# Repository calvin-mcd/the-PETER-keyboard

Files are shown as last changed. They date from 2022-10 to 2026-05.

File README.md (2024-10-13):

# the PETER keyboard

compact 60ish keyboard inspired by 40s layouts & formfactors

I designed this keyboard after asking my friend Peter what his ideal keyboard would be. His answer was:"Ehm... I like numbers!". So I tried to make a board that keeps the functionality of a 60% keyboard while offering it in a 40s inspired form factor.

It takes inspiration from ai03’s [UT47.2](https://github.com/ai03-2725/UT47.2) and EODesigns\#4352’s [Humble40](https://geekhack.org/index.php?topic=112927.0) as well as trash man\#6005’s [v4n4g0n](https://trashman.wiki/keyboards/v4n4g0n) and NoahK\#1290’s [Monorail](https://trashman.wiki/community/pcbs/monorail) pcbs.

The case is based on rain\#3950's [mfr2](https://github.com/rainkeebs/mfr2) and has been edited by Gizzle\#9369 to allow for bottom mounting inspired by projectcain\#5265's [vault35](https://mechvault.net/products/vault-35-mini-keyboard)

## Layout

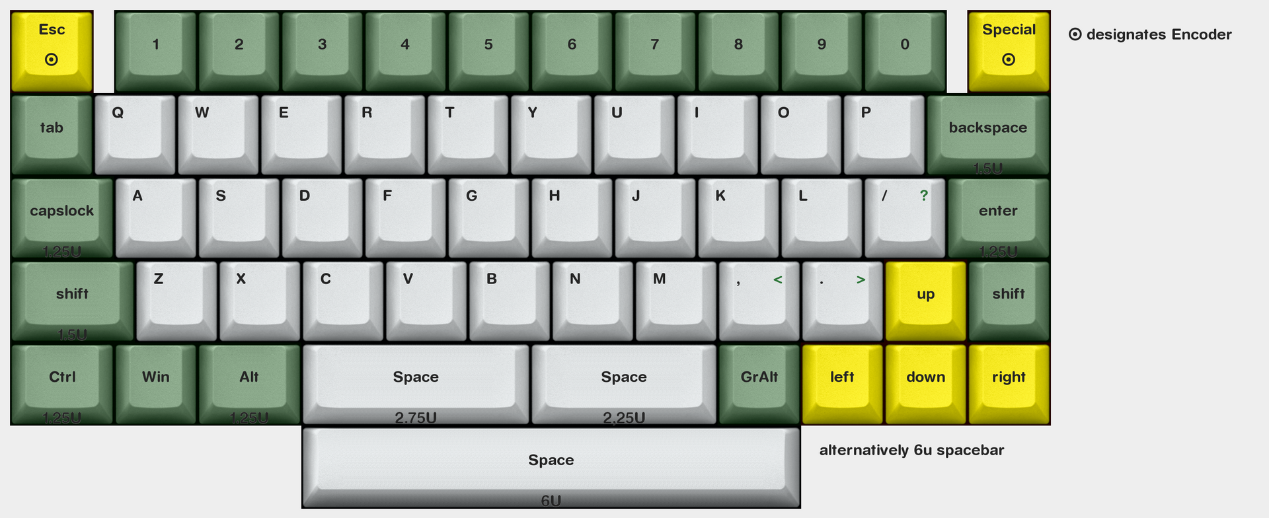
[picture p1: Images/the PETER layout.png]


[Link](https://www.keyboard-layout-editor.com/#/gists/bfbfb0e68d74f1cbb328a13727df050d)

## Pictures

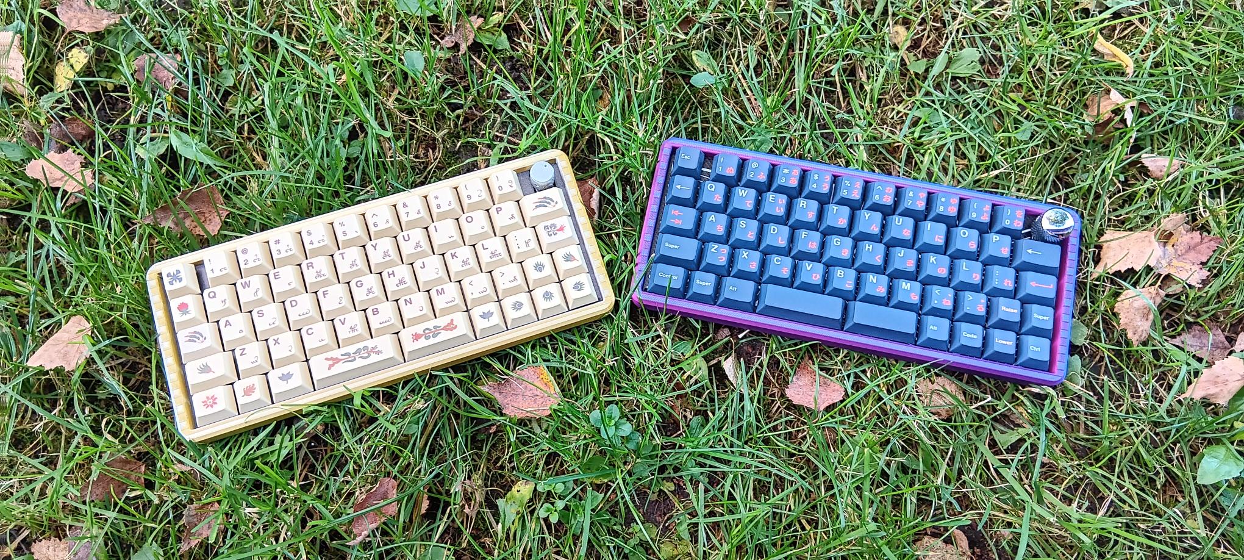
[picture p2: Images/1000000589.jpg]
  
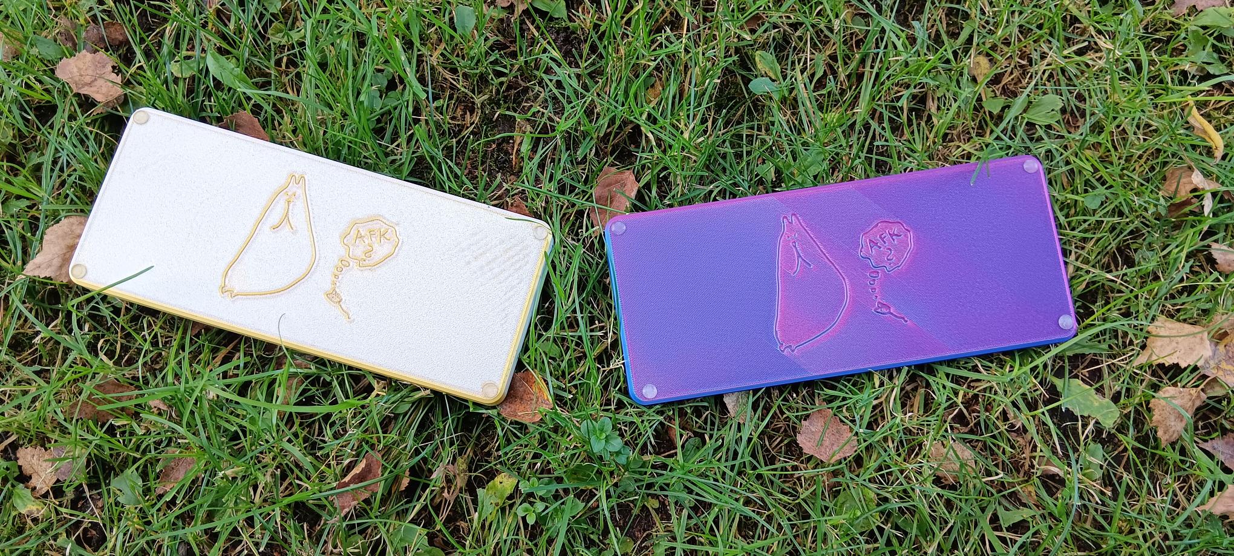
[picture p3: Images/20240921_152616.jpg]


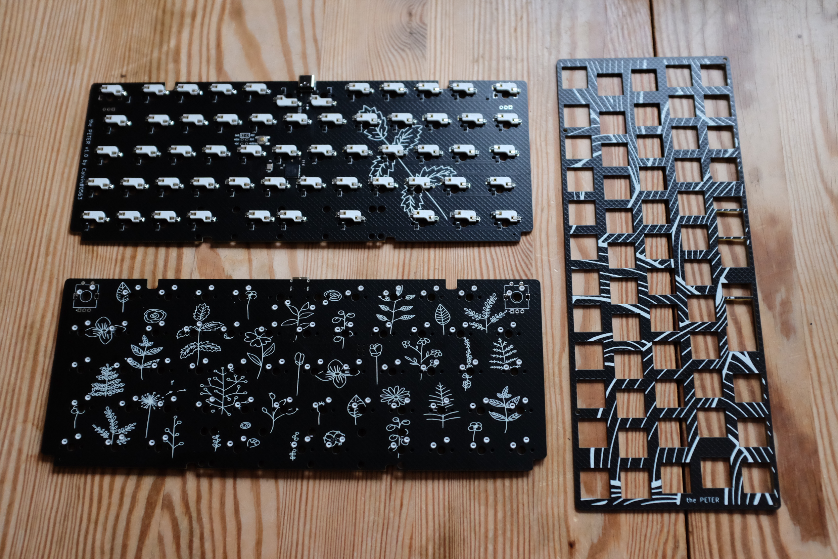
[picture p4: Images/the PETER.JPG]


## Disclaimer

This project has been tested and confirmed to work. However, no-one involved in this project is responsible for any usage issues that may arise. Order at your own risk. Feel free to edit, modify and otherwise utilise these files.

## License

This project is released under the GPL v3 License. Please refer to the LICENCE file.

## Credits

As always big thanks to the many people who helped me with the pcb, firmware, case design and much more! Escpecially NoahK\#1290, Gizzle\#9369, Iceage\#8817, Dana\#5035, Sierry\#7140 & TweetyDaBird\#3276!

Any questions, contact Calvin\#0563 on Discord.

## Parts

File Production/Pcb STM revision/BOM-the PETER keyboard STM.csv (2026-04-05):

Comment | Designator | Footprint | LCSC | Quantity
100nF | C1,C2,C3,C4,C5,C7 | C_0402_1005Metric | C307331 | 6
10k | R1 | R_0402_1005Metric | C25744 | 1
10uF | C6 | C_0402_1005Metric | C15525 | 1
1uF | C8,C9 | C_0402_1005Metric | C52923 | 2
500mA | F1 | Fuse_1206_3216Metric | C70076 | 1
5k1 | R2,R3 | R_0402_1005Metric | C25905 | 2
D_Small | D1,D10,D11,D12,D13,D14,D15,D16,D17,D18,D19,D2,D20,D21,D22,D23,D24,D25,D26,D27,D28,D29,D3,D30,D31,D32,D33,D34,D35,D36,D37,D38,D39,D4,D40,D41,D42,D43,D44,D45,D46,D47,D48,D49,D5,D50,D51,D52,D53,D54,D55,D56,D57,D58,D6,D7,D8,D9 | D_SOD-123F | C64898 | 58
SKQGABE010 | SW3 | SW_Push_SPST_NO_Alps_SKRK | C115357 | 1
SMF9.0CA | D_PWR1 | D_SOD-123 | C707469 | 1
STM32F072C8Tx | U2 | LQFP-48_7x7mm_P0.5mm | C81720 | 1
USBLC6-2SC6 | U4 | SOT-23-6 | C2827654 | 1
USB_C_Receptacle_USB2.0 | J3 | USB_C_Receptacle_HRO_TYPE-C-31-M-12 | C165948 | 1
XC6206PxxxMR-Regulator_Linear | U3 | SOT-23 | C5446 | 1

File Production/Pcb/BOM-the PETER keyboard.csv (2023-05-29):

Comment | Designator | Footprint | LCSC
22pF | C_crystal1,C_crystal2 | C_0402_1005Metric | C106203
ATmega32U4-M | U1 | QFN-44-1EP_7x7mm_P0.5mm_EP5.2x5.2mm | C112161
Crystal_GND24_Small | Y1 | Crystal_SMD_3225-4Pin_3.2x2.5mm | C133336
0.1uF | C_Decoupler1,C_Decoupler2,C_Decoupler3,C_Decoupler5 | C_0402_1005Metric | C1525
4.7nF | C_USBSHIELD1 | C_0402_1005Metric | C1538
USB_C_Receptacle_USB2.0 | J1 | USB_C_Receptacle_HRO_TYPE-C-31-M-12 | C165948
1uF | C_UCAP1 | C_0402_1005Metric | C182246
10uF | C_Decoupler4 | C_0402_1005Metric | C237279
22ohm | R_USB3,R_USB4 | R_0402_1005Metric | C25092
5.1k | R_USB1,R_USB2 | R_0402_1005Metric | C25905
PRTR5V0U2X | D59 | SOT-143 | C2827688
10k | R_reset1 | R_0402_1005Metric | C3015825
1M | R_USBSHIELD1 | R_0402_1005Metric | C3015928
SW_Push | SW2 | SKQG-1155865 | C318884
D_Small | D1,D10,D11,D12,D13,D14,D15,D16,D17,D18,D19,D2,D20,D21,D22,D23,D24,D25,D26,D27,D28,D29,D3,D30,D31,D32,D33,D34,D35,D36,D37,D38,D39,D4,D40,D41,D42,D43,D44,D45,D46,D47,D48,D49,D5,D50,D51,D52,D53,D54,D55,D56,D57,D58,D6,D7,D8,D9 | D_SOD-123F | C64898
500mA | F_USBC1 | Fuse_1206_3216Metric | C70076
MountingHole | H4 | MountingHole_2.2mm_M2
MountingHole | H3 | MountingHole_2.2mm_M2
MountingHole | H1 | MountingHole_2.2mm_M2
MountingHole | H2 | MountingHole_2.2mm_M2
MX-NoLED | MX56 | MXOnly-1U-Hotswap
MX-NoLED | MX51 | MXOnly-1.25U-Hotswap
MX-NoLED | MX52 | MXOnly-2.75U-Hotswap-ReversedStabilizers
MX-NoLED | MX13 | MXOnly-1U-Hotswap
MX-NoLED | MX37 | MXOnly-1.5U-Hotswap
MX-NoLED | MX19 | MXOnly-1U-Hotswap
MX-NoLED | MX54 | MXOnly-2.25U-Hotswap-ReversedStabilizers
MX-NoLED | MX7 | MXOnly-1U-Hotswap
MX-NoLED | MX46 | MXOnly-1U-Hotswap
RotaryEncoder_Switch | SW1 | RotaryEncoder_Alps_EC11E-Switch_Vertical_H20mm
MX-NoLED | MX48 | MXOnly-1U-Hotswap
MX-NoLED | MX14 | MXOnly-1U-Hotswap
MX-NoLED | MX12 | MXOnly-1U-Hotswap
MX-NoLED | MX30 | MXOnly-1U-Hotswap
MX-NoLED | MX15 | MXOnly-1U-Hotswap
MX-NoLED | MX26 | MXOnly-1U-Hotswap
MX-NoLED | MX11 | MXOnly-1U-Hotswap
MX-NoLED | MX45 | MXOnly-1U-Hotswap
MX-NoLED | MX18 | MXOnly-1U-Hotswap
MX-NoLED | MX32 | MXOnly-1U-Hotswap
MX-NoLED | MX22 | MXOnly-1U-Hotswap
MountingHole | H5 | MountingHole_2.2mm_M2
MX-NoLED | MX35 | MXOnly-1U-Hotswap
MX-NoLED | MX27 | MXOnly-1U-Hotswap
MX-NoLED | MX43 | MXOnly-1U-Hotswap
MX-NoLED | MX3 | MXOnly-1U-Hotswap
MX-NoLED | MX33 | MXOnly-1U-Hotswap
MX-NoLED | MX50 | MXOnly-1U-Hotswap
MX-NoLED | MX47 | MXOnly-1U-Hotswap
MX-NoLED | MX28 | MXOnly-1U-Hotswap
MX-NoLED | MX6 | MXOnly-1U-Hotswap
MX-NoLED | MX49 | MXOnly-1.25U-Hotswap
MX-NoLED | MX10 | MXOnly-1U-Hotswap
MX-NoLED | MX8 | MXOnly-1U-Hotswap
MX-NoLED | MX9 | MXOnly-1U-Hotswap
MX-NoLED | MX42 | MXOnly-1U-Hotswap
MX-NoLED | MX24 | MXOnly-1.5U-Hotswap
MX-NoLED | MX20 | MXOnly-1U-Hotswap
MX-NoLED | MX1 | MXOnly-1U-Hotswap
MX-NoLED | MX16 | MXOnly-1U-Hotswap
MX-NoLED | MX38 | MXOnly-1U-Hotswap
MX-NoLED | MX31 | MXOnly-1U-Hotswap
MountingHole | H6 | MountingHole_2.2mm_M2
MX-NoLED | MX53 | MXOnly-6U-Centered-Hotswap-ReversedStabilizers
MX-NoLED | MX29 | MXOnly-1U-Hotswap
MX-NoLED | MX39 | MXOnly-1U-Hotswap
MX-NoLED | MX55 | MXOnly-1U-Hotswap
MX-NoLED | MX40 | MXOnly-1U-Hotswap
MX-NoLED | MX21 | MXOnly-1U-Hotswap
MX-NoLED | MX5 | MXOnly-1U-Hotswap
MX-NoLED | MX44 | MXOnly-1U-Hotswap
MX-NoLED | MX36 | MXOnly-1.25U-Hotswap
RotaryEncoder_Switch | SW12 | RotaryEncoder_Alps_EC11E-Switch_Vertical_H20mm
MX-NoLED | MX4 | MXOnly-1U-Hotswap
MX-NoLED | MX25 | MXOnly-1.25U-Hotswap
MX-NoLED | MX17 | MXOnly-1U-Hotswap
MX-NoLED | MX41 | MXOnly-1U-Hotswap
MX-NoLED | MX34 | MXOnly-1U-Hotswap
MX-NoLED | MX58 | MXOnly-1U-Hotswap
MX-NoLED | MX2 | MXOnly-1U-Hotswap
MX-NoLED | MX57 | MXOnly-1U-Hotswap
MX-NoLED | MX23 | MXOnly-1U-Hotswap
AVR-ISP-6 | J2 | Reset_Pretty-Mask

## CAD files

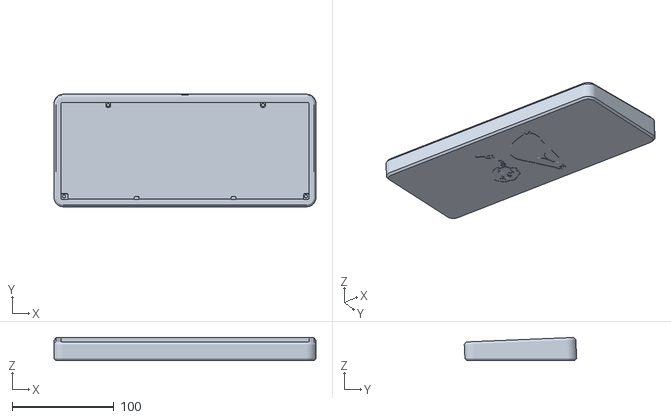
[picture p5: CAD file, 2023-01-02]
Case/mfr2_v43.stl
257.9 x 110.8 x 22.9

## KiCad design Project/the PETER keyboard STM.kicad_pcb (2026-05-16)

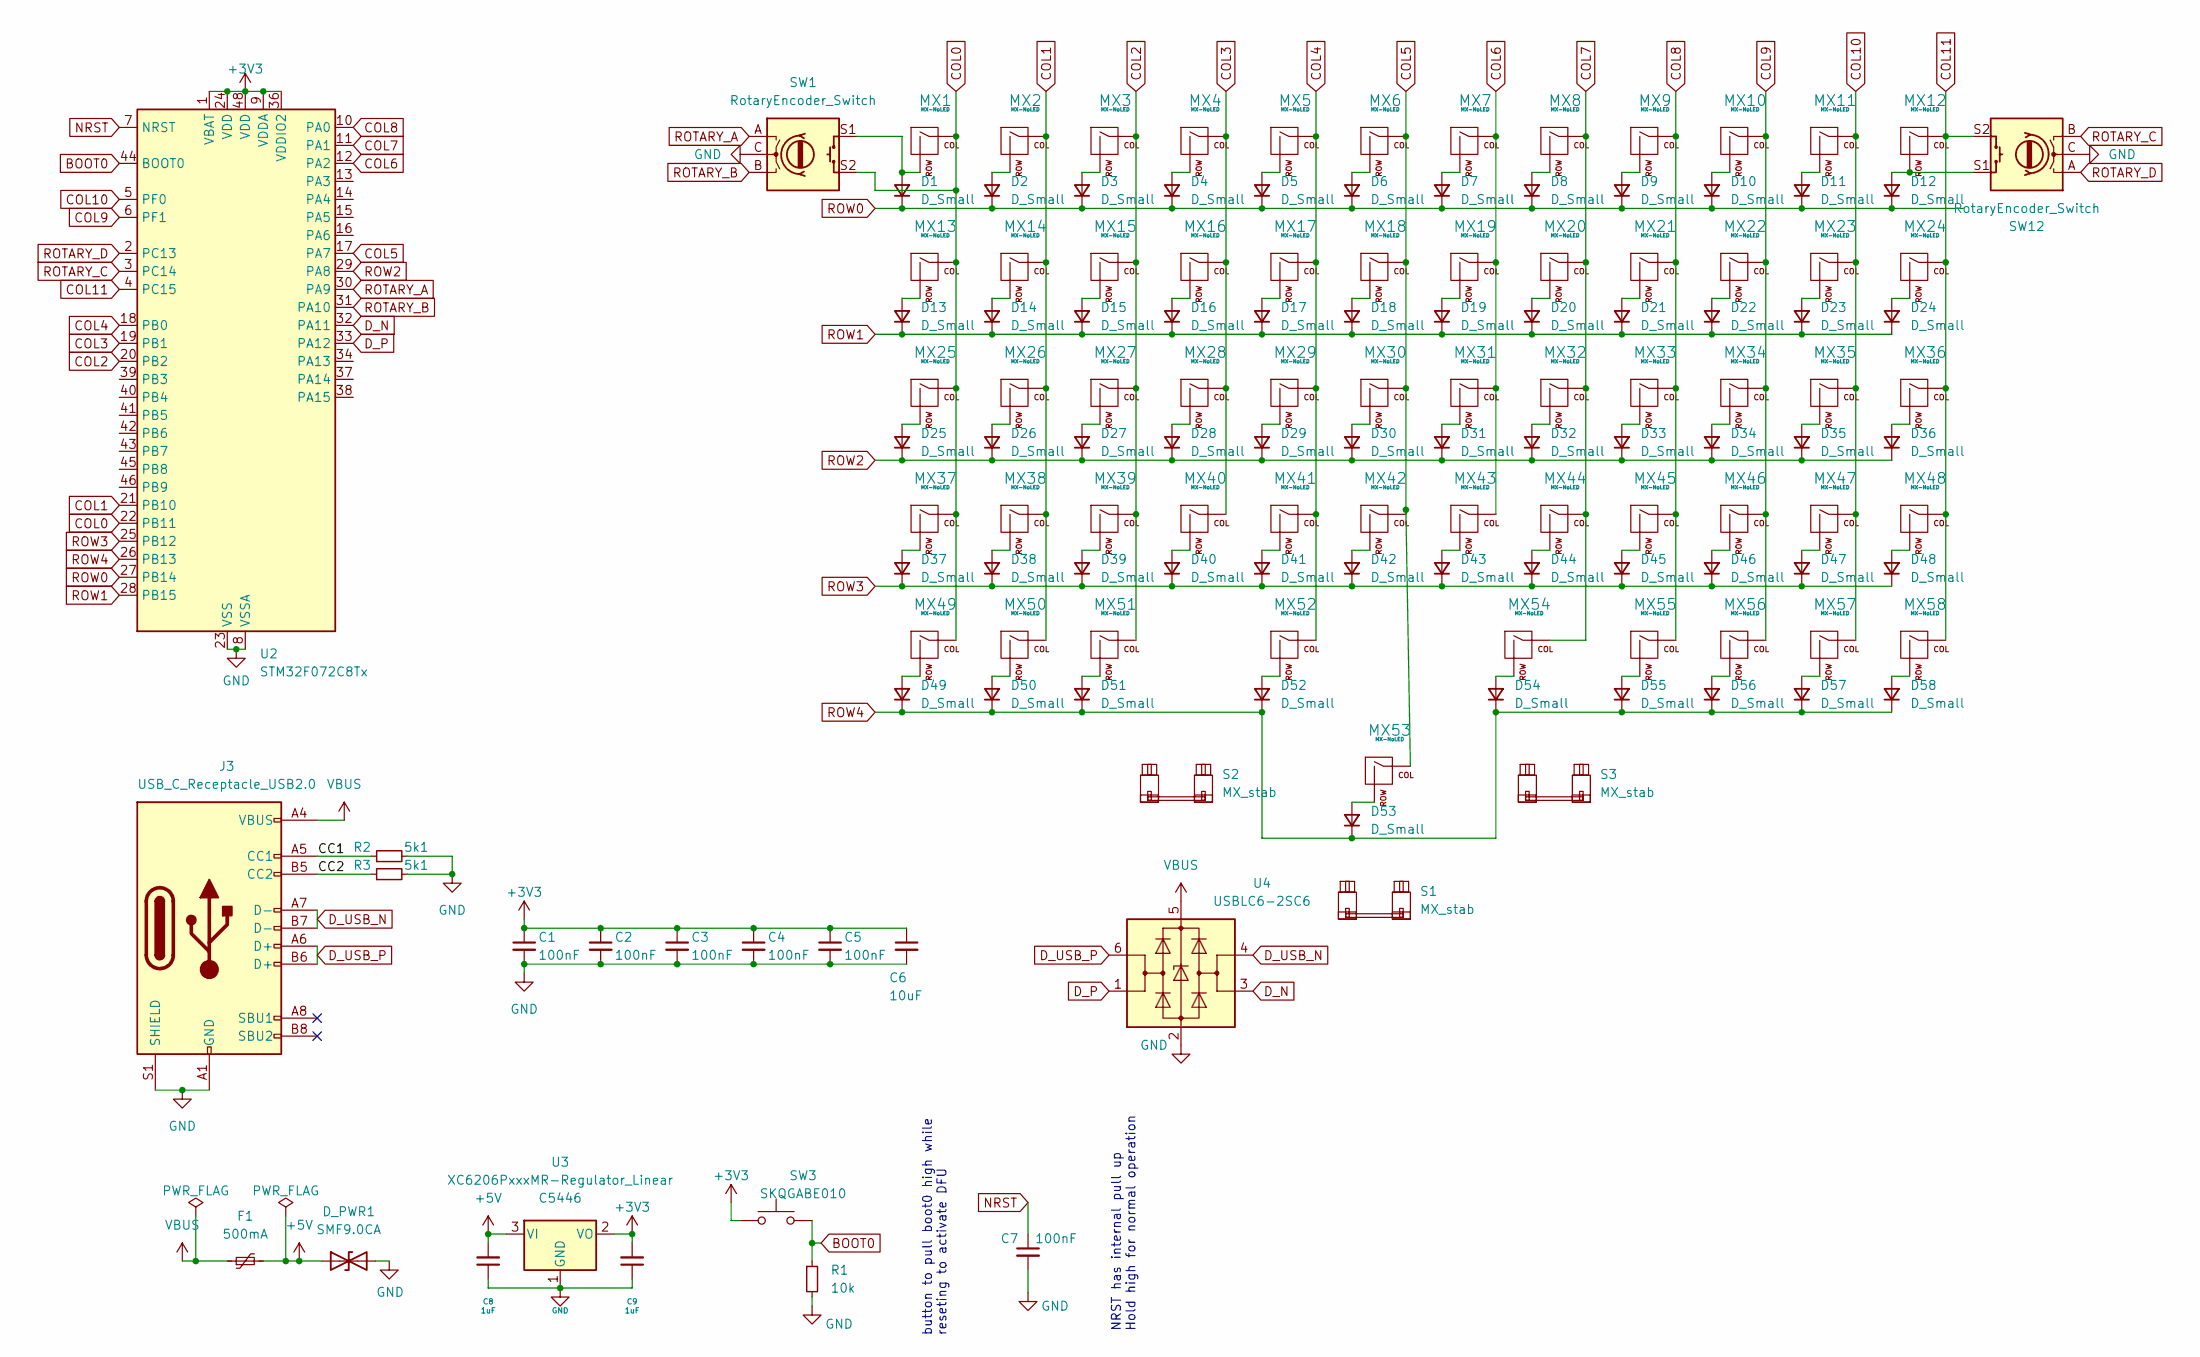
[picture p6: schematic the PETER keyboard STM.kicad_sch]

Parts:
C1, C2, C3, C4, C5: 100nF; C_0402_1005Metric
C6: 10uF; C_0402_1005Metric
C7: 100nF; C_0402_1005Metric; LCSC C307331
C8, C9: 1uF; C_0402_1005Metric; LCSC C52923
D1, D2, D3, D4, D5, D6, D7, D8, D9, D10, D11, D12, D13, D14, D15, D16, D17, D18, D19, D20, D21, D22, D23, D24, D25, D26, D27, D28, D29, D30, D31, D32, D33, D34, D35, D36, D37, D38, D39, D40, D41, D42, D43, D44, D45, D46, D47, D48, D49, D50, D51, D52, D53, D54, D55, D56, D57, D58: D_Small; D_SOD-123F
D_PWR1: SMF9.0CA; D_SOD-123
F1: 500mA; Fuse_1206_3216Metric; LCSC C70076
J3: USB_C_Receptacle_USB2.0; USB_C_Receptacle_HRO_TYPE-C-31-M-12; LCSC C165948
MX1, MX2, MX3, MX4, MX5, MX6, MX7, MX8, MX9, MX10, MX11, MX12, MX13, MX14, MX15, MX16, MX17, MX18, MX19, MX20, MX21, MX22, MX23, MX26, MX27, MX28, MX29, MX30, MX31, MX32, MX33, MX34, MX35, MX38, MX39, MX40, MX41, MX42, MX43, MX44, MX45, MX46, MX47, MX48, MX50, MX52, MX53, MX54, MX55, MX56, MX57, MX58: MX-NoLED; SW_MX_HS_S_CPG151101S11_1u
MX24, MX37: MX-NoLED; SW_MX_HS_CPG151101S11_1.5u
MX25, MX36, MX49, MX51: MX-NoLED; SW_MX_HS_CPG151101S11_1.25u
R1: 10k; R_0402_1005Metric
R2, R3: 5k1; R_0402_1005Metric; LCSC C25905
S1: MX_stab; STAB_MX_P_6u
S2: MX_stab; STAB_MX_P_2.25u
S3: MX_stab; STAB_MX_P_2.75u
SW1, SW12: RotaryEncoder_Switch; ROT_Alps_EC11E-Switch
SW3: SKQGABE010; SW_Push_SPST_NO_Alps_SKRK; LCSC C115351
U2: STM32F072C8Tx; LQFP-48_7x7mm_P0.5mm
U3: XC6206PxxxMR-Regulator_Linear; SOT-23; LCSC C5446
U4: USBLC6-2SC6; SOT-23-6; LCSC C2827654

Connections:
+3V3: C1.1, C2.1, C3.1, C4.1, C5.1, C6.1, C9.2, SW3.1, U2.1 (VBAT), U2.9 (VDDA), U2.24 (VDD), U2.36 (VDDIO2), U2.48 (VDD), U3.2 (VO)
+5V: C8.2, D_PWR1.1 (A1), F1.2, U3.3 (VI)
/CC1: J3.A5 (CC1), R2.1
/CC2: J3.B5 (CC2), R3.1
BOOT0: R1.1, SW3.2, U2.44 (BOOT0)
COL0: MX1.1 (COL), MX13.1 (COL), MX25.1 (COL), MX37.1 (COL), MX49.1 (COL), SW1.S2, U2.22 (PB11)
COL1: MX2.1 (COL), MX14.1 (COL), MX26.1 (COL), MX38.1 (COL), MX50.1 (COL), U2.21 (PB10)
COL2: MX3.1 (COL), MX15.1 (COL), MX27.1 (COL), MX39.1 (COL), MX51.1 (COL), U2.20 (PB2)
COL3: MX4.1 (COL), MX16.1 (COL), MX28.1 (COL), MX40.1 (COL), U2.19 (PB1)
COL4: MX5.1 (COL), MX17.1 (COL), MX29.1 (COL), MX41.1 (COL), MX52.1 (COL), U2.18 (PB0)
COL5: MX6.1 (COL), MX18.1 (COL), MX30.1 (COL), MX42.1 (COL), MX53.1 (COL), U2.17 (PA7)
COL6: MX7.1 (COL), MX19.1 (COL), MX31.1 (COL), MX43.1 (COL), U2.12 (PA2)
COL7: MX8.1 (COL), MX20.1 (COL), MX32.1 (COL), MX44.1 (COL), MX54.1 (COL), U2.11 (PA1)
COL8: MX9.1 (COL), MX21.1 (COL), MX33.1 (COL), MX45.1 (COL), MX55.1 (COL), U2.10 (PA0)
COL9: MX10.1 (COL), MX22.1 (COL), MX34.1 (COL), MX46.1 (COL), MX56.1 (COL), U2.6 (PF1)
COL10: MX11.1 (COL), MX23.1 (COL), MX35.1 (COL), MX47.1 (COL), MX57.1 (COL), U2.5 (PF0)
COL11: MX12.1 (COL), MX24.1 (COL), MX36.1 (COL), MX48.1 (COL), MX58.1 (COL), SW12.S2, U2.4 (PC15)
D_N: U2.32 (PA11), U4.3 (I/O2)
D_P: U2.33 (PA12), U4.1 (I/O1)
D_USB_N: J3.A7 (D-), J3.B7 (D-), U4.4 (I/O2)
D_USB_P: J3.A6 (D+), J3.B6 (D+), U4.6 (I/O1)
GND: C1.2, C2.2, C3.2, C4.2, C5.2, C6.2, C7.2, C8.1, C9.1, D_PWR1.2 (A2), J3.A1 (GND), J3.A12 (GND), J3.B1 (GND), J3.B12 (GND), J3.S1 (SHIELD), R1.2, R2.2, R3.2, SW1.C, SW12.C, U2.8 (VSSA), U2.23 (VSS), U2.35 (VSS), U2.47 (VSS), U3.1 (GND), U4.2 (GND)
NRST: C7.1, U2.7 (NRST)
unnamed: D1.2 (A), MX1.2 (ROW), SW1.S1
unnamed: D2.2 (A), MX2.2 (ROW)
unnamed: D3.2 (A), MX3.2 (ROW)
unnamed: D4.2 (A), MX4.2 (ROW)
unnamed: D5.2 (A), MX5.2 (ROW)
unnamed: D6.2 (A), MX6.2 (ROW)
unnamed: D7.2 (A), MX7.2 (ROW)
unnamed: D8.2 (A), MX8.2 (ROW)
unnamed: D9.2 (A), MX9.2 (ROW)
unnamed: D10.2 (A), MX10.2 (ROW)
unnamed: D11.2 (A), MX11.2 (ROW)
unnamed: D12.2 (A), MX12.2 (ROW), SW12.S1
unnamed: D13.2 (A), MX13.2 (ROW)
unnamed: D14.2 (A), MX14.2 (ROW)
unnamed: D15.2 (A), MX15.2 (ROW)
unnamed: D16.2 (A), MX16.2 (ROW)
unnamed: D17.2 (A), MX17.2 (ROW)
unnamed: D18.2 (A), MX18.2 (ROW)
unnamed: D19.2 (A), MX19.2 (ROW)
unnamed: D20.2 (A), MX20.2 (ROW)
unnamed: D21.2 (A), MX21.2 (ROW)
unnamed: D22.2 (A), MX22.2 (ROW)
unnamed: D23.2 (A), MX23.2 (ROW)
unnamed: D24.2 (A), MX24.2 (ROW)
unnamed: D25.2 (A), MX25.2 (ROW)
unnamed: D26.2 (A), MX26.2 (ROW)
unnamed: D27.2 (A), MX27.2 (ROW)
unnamed: D28.2 (A), MX28.2 (ROW)
unnamed: D29.2 (A), MX29.2 (ROW)
unnamed: D30.2 (A), MX30.2 (ROW)
unnamed: D31.2 (A), MX31.2 (ROW)
unnamed: D32.2 (A), MX32.2 (ROW)
unnamed: D33.2 (A), MX33.2 (ROW)
unnamed: D34.2 (A), MX34.2 (ROW)
unnamed: D35.2 (A), MX35.2 (ROW)
unnamed: D36.2 (A), MX36.2 (ROW)
unnamed: D37.2 (A), MX37.2 (ROW)
unnamed: D38.2 (A), MX38.2 (ROW)
unnamed: D39.2 (A), MX39.2 (ROW)
unnamed: D40.2 (A), MX40.2 (ROW)
unnamed: D41.2 (A), MX41.2 (ROW)
unnamed: D42.2 (A), MX42.2 (ROW)
unnamed: D43.2 (A), MX43.2 (ROW)
unnamed: D44.2 (A), MX44.2 (ROW)
unnamed: D45.2 (A), MX45.2 (ROW)
unnamed: D46.2 (A), MX46.2 (ROW)
unnamed: D47.2 (A), MX47.2 (ROW)
unnamed: D48.2 (A), MX48.2 (ROW)
unnamed: D49.2 (A), MX49.2 (ROW)
unnamed: D50.2 (A), MX50.2 (ROW)
unnamed: D51.2 (A), MX51.2 (ROW)
unnamed: D52.2 (A), MX52.2 (ROW)
unnamed: D53.2 (A), MX53.2 (ROW)
unnamed: D54.2 (A), MX54.2 (ROW)
unnamed: D55.2 (A), MX55.2 (ROW)
unnamed: D56.2 (A), MX56.2 (ROW)
unnamed: D57.2 (A), MX57.2 (ROW)
unnamed: D58.2 (A), MX58.2 (ROW)
ROTARY_A: SW1.A, U2.30 (PA9)
ROTARY_B: SW1.B, U2.31 (PA10)
ROTARY_C: SW12.B, U2.3 (PC14)
ROTARY_D: SW12.A, U2.2 (PC13)
ROW0: D1.1 (K), D2.1 (K), D3.1 (K), D4.1 (K), D5.1 (K), D6.1 (K), D7.1 (K), D8.1 (K), D9.1 (K), D10.1 (K), D11.1 (K), D12.1 (K), U2.27 (PB14)
ROW1: D13.1 (K), D14.1 (K), D15.1 (K), D16.1 (K), D17.1 (K), D18.1 (K), D19.1 (K), D20.1 (K), D21.1 (K), D22.1 (K), D23.1 (K), D24.1 (K), U2.28 (PB15)
ROW2: D25.1 (K), D26.1 (K), D27.1 (K), D28.1 (K), D29.1 (K), D30.1 (K), D31.1 (K), D32.1 (K), D33.1 (K), D34.1 (K), D35.1 (K), D36.1 (K), U2.29 (PA8)
ROW3: D37.1 (K), D38.1 (K), D39.1 (K), D40.1 (K), D41.1 (K), D42.1 (K), D43.1 (K), D44.1 (K), D45.1 (K), D46.1 (K), D47.1 (K), D48.1 (K), U2.25 (PB12)
ROW4: D49.1 (K), D50.1 (K), D51.1 (K), D52.1 (K), D53.1 (K), D54.1 (K), D55.1 (K), D56.1 (K), D57.1 (K), D58.1 (K), U2.26 (PB13)
VBUS: F1.1, J3.A4 (VBUS), J3.A9 (VBUS), J3.B4 (VBUS), J3.B9 (VBUS), U4.5 (VBUS)

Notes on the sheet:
button to pull boot0 high while reseting to activate DFU
NRST has internal pull up Hold high for normal operation

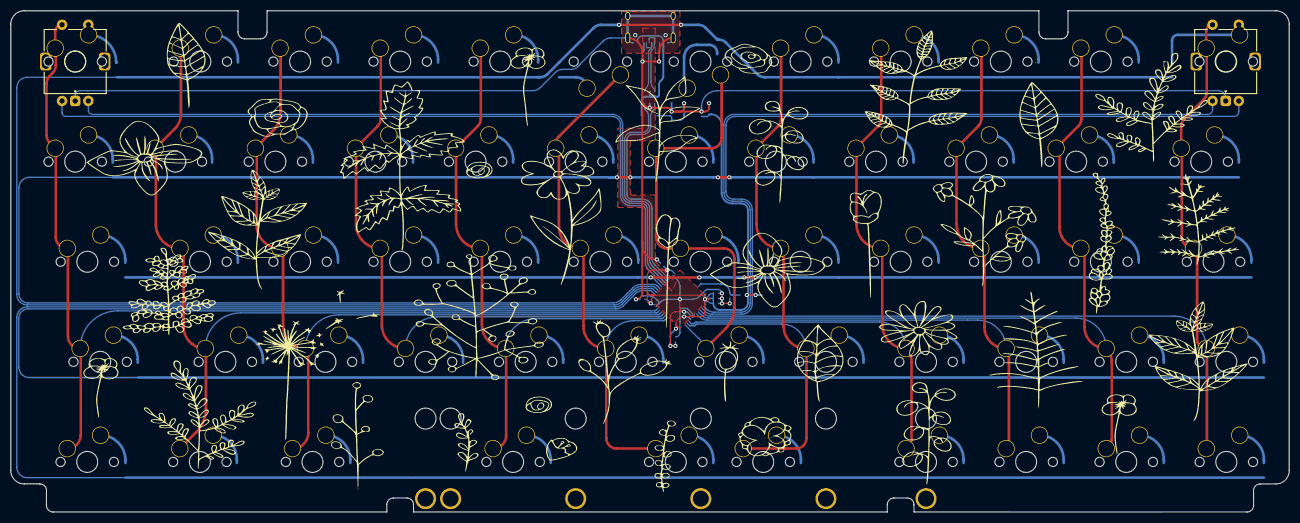
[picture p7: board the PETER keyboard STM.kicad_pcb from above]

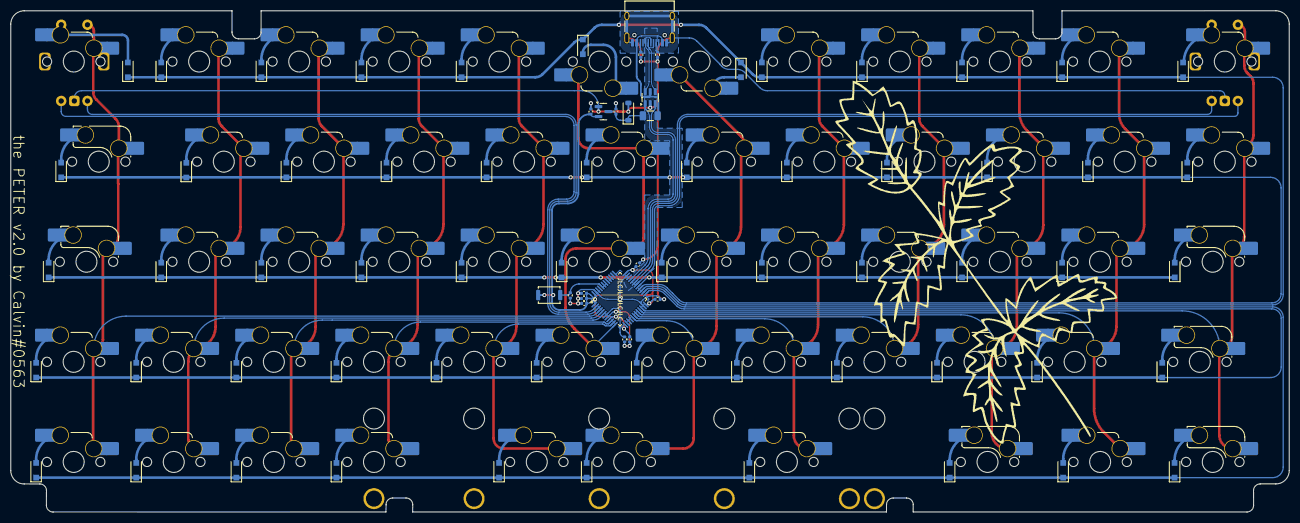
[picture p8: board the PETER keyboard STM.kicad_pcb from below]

Board: 2 copper layers, 243.3 x 95.4 mm, 140 parts (135 on the bottom side), 91 nets.

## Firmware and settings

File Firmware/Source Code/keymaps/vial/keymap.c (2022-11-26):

#include QMK_KEYBOARD_H

const uint16_t PROGMEM keymaps[][MATRIX_ROWS][MATRIX_COLS] = {
    [0] = LAYOUT(
        KC_NO,   KC_NO,   KC_NO,   KC_NO,   KC_NO,   KC_NO,   KC_NO,   KC_NO,   KC_NO,   KC_NO,   KC_NO,   KC_NO,
        KC_NO,   KC_NO,   KC_NO,   KC_NO,   KC_NO,   KC_NO,   KC_NO,   KC_NO,   KC_NO,   KC_NO,   KC_NO,   KC_NO,
        KC_NO,   KC_NO,   KC_NO,   KC_NO,   KC_NO,   KC_NO,   KC_NO,   KC_NO,   KC_NO,   KC_NO,   KC_NO,   KC_NO,
        KC_NO,   KC_NO,   KC_NO,   KC_NO,   KC_NO,   KC_NO,   KC_NO,   KC_NO,   KC_NO,   KC_NO,   KC_NO,   KC_NO,
        KC_NO,   KC_NO,   KC_NO,                     KC_NO,                              KC_NO,   KC_NO,   KC_NO
    )
};

/* Encoder */ 
const uint16_t PROGMEM encoder_map[][NUM_ENCODERS][2] = {
    [0] = { ENCODER_CCW_CW(KC_NO, KC_NO), ENCODER_CCW_CW(KC_NO, KC_NO) }
};

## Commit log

2022-09-26 Setting up the project
    [the PETER keyboard.kicad_pcb, the PETER keyboard.kicad_sch]
2022-09-26 MCU set up
    MCU and USB set up
    [the PETER keyboard.kicad_sch]
2022-09-26 starting to set up matrix
    [the PETER keyboard.kicad_sch]
2022-09-26 switch matrix set up complete
    whole switch matrix,
    but no rotary encoders yet,
    no usb c
    [the PETER keyboard.kicad_sch]
2022-09-26 schematics for USB C added
    shielding not complete
    [the PETER keyboard.kicad_sch]
2022-09-26 added first draft of rotary encoders
    not confirmed to work
    [the PETER keyboard.kicad_sch]
2022-09-26 USB c cleaned up
    older USB port removed
    [the PETER keyboard.kicad_sch]
2022-09-26 footprints assigned to schematics
    [the PETER keyboard.kicad_sch]
2022-09-27 PCB editor
    placing switch matrix
    [the PETER keyboard.kicad_pcb]
2022-09-27 Switches and Diodes placed, margins assigned
    still need to figure out placement of usb, and MCU
    [the PETER keyboard.kicad_pcb]
2022-09-27 matrix tracing
    [the PETER keyboard.kicad_pcb]
2022-09-27 starting mcu traces
    [the PETER keyboard.kicad_pcb]
2022-09-27 reworked DSM placement, exchanged MCU for smaller
    [the PETER keyboard.kicad_pcb, the PETER keyboard.kicad_sch]
2022-09-28 trying to trace mcu, usb
    no success yet
    [the PETER keyboard.kicad_pcb, the PETER keyboard.kicad_sch]
2022-09-28 more attempts at changing mcu
    [the PETER keyboard.kicad_pcb]
2022-09-29 placed MCU and USB for automatic routing
    also assigned row and col to MCU
    [the PETER keyboard.kicad_pcb, the PETER keyboard.kicad_sch]
2022-09-30 traces have been auto routed
    [the PETER keyboard here we go again.dsn, the PETER keyboard moved rotary encoders, all traces deleted.dsn, the PETER keyboard moved rotary encoders.dsn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]
2022-09-30 re doing the auto routing
    having to start again
    [the PETER keyboard 45.dsn, the PETER keyboard next day.dsn, the PETER keyboard.kicad_pcb]
2022-09-30 back to autorouting
    [the PETER keyboard 45.dsn, the PETER keyboard here we go again.dsn, the PETER keyboard moved rotary encoders, all traces deleted.dsn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]
2022-09-30 moving MCU around, no trace attempt yet
    [the PETER keyboard.kicad_pcb]
2022-09-30 just checking in on the files
    [the PETER keyboard1.dsn]
2022-10-01 just tried and deleted a silkscreen
    [the PETER keyboard.kicad_pcb]
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2022-10-02 reworking pcb placement according to schematics
    [the PETER keyboard.kicad_pcb, the PETER keyboard2.dsn]
2022-10-02 manual routing
    [the PETER keyboard.kicad_pcb]
2022-10-03 traces added for rows and columns
    rotary encoders are still left
    [the PETER keyboard.dsn, the PETER keyboard.kicad_sch]
2022-10-04 starting to redo mcu and usb
    [the PETER keyboard.kicad_sch]
2022-10-07 cleaned up MCU, USB. Connected rows. Assigned to MCU. now routing rows & cols
    [the PETER keyboard.kicad_sch]
2022-10-07 all traces routed
    no curves, no grounding routes drawn
    [the PETER keyboard.dsn, the PETER keyboard.kicad_sch]
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2022-10-08 created a switchplate
    [the PETER switchplate.kicad_pcb]
2022-10-08 switchplate clean up
    [the PETER switchplate.kicad_pcb]
2022-10-09 created gerbers, added front silkscreen, cleaned up folder
    [the PETER keyboard-B_Cu.gbr, the PETER keyboard-B_Mask.gbr, the PETER keyboard-B_Silkscreen.gbr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]
2022-10-09 generate gerber for plate file
    [the PETER switchplate-B_Cu.gbr, the PETER switchplate-B_Mask.gbr, the PETER switchplate-B_Silkscreen.gbr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]
2022-10-11 planning m2 holes and relief cuts
    [the PETER switchplate.kicad_pcb]
2022-10-11 planning out m2 and relief cuts
    [the PETER switchplate.kicad_pcb]
2022-10-20 added hotswap and mounting holes for reference
    need to add cuts to pcb, reroute matrix and usb, mcu
    [PETER plate.dxf, the PETER keyboard.kicad_sch]
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2022-10-22 rerouting, plate cuts
    rerouted mcu, usb, all rows and cols. added plate cuts for bottom mounting
    [#PETER plate.dxf, the PETER keyboard.kicad_sch]
2022-10-22 routing done
    all routing done, curves added. 6u swapped for hotswap again. STABILIZERS NOT CHANGED YET
    [the PETER keyboard.kicad_sch]
2022-10-22 cleaned pcb, cleaned switchplate
    [the PETER keyboard.kicad_sch]
2022-10-22 deleted unnecessary files
    [#PETER plate.dxf, PETER plate.dxf, the PETER switchplate.kicad_pcb]
2022-10-22 pcb, plate cleaned
    stabs reversed
    [the PETER keyboard.kicad_sch, the PETER switchplate.kicad_pcb]
2022-10-25 gnd fill changed, bottom mounting changed
    switchplate has not been adapted, routing not working
    [the PETER keyboard.kicad_sch]
2022-10-25 edgecut pcb updated, switchplate updated
    [the PETER switchplate.kicad_pcb]
2022-10-25 changes to pcb, plate, DRC cleanup
    [the PETER keyboard-B_Cu.gbr, the PETER keyboard-B_Mask.gbr, the PETER keyboard-B_Silkscreen.gbr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]
2022-10-25 created production files for all parts
    parts list still missing
    [the PETER switchplate-B_Cu.gbr, the PETER switchplate-B_Mask.gbr, the PETER switchplate-B_Silkscreen.gbr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]
2022-10-26 created BOM, POS, production files for JLC
    [BOM-the PETER keyboard.csv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]
2022-10-27 changing silkscreen to fit edge cuts
    for production files
    [POS-the PETER keyboard.csv, the PETER keyboard-CuBottom.gbr, the PETER keyboard-CuTop.gbr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]
2022-10-27 adapting gerbers
    [the PETER keyboard-B_Cu.gbr, the PETER keyboard-B_Mask.gbr, the PETER keyboard-B_Silkscreen.gbr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]
2022-10-27 production updated
    [BOM-the PETER keyboard.csv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]
2022-10-29 generating fresh POM&POS files for production
    [BOM-the PETER keyboard.csv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]
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2022-11-10 updated BOM with correct crystal
    [BOM-the PETER keyboard.csv]
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2022-11-26 completing project, cleaning folders
    [BOM-the PETER keyboard.csv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]
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2023-05-29 updated BOM with correct parts
    [BOM-the PETER keyboard.csv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]
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2026-04-19 kicad 9
    gnd zones
    [the PETER keyboard STM-B_Cu.gbr, the PETER keyboard STM-B_Mask.gbr, the PETER keyboard STM-B_Silkscreen.gbr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]
